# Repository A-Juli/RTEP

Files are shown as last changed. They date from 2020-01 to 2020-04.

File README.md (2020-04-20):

# Yet Another Glove project 

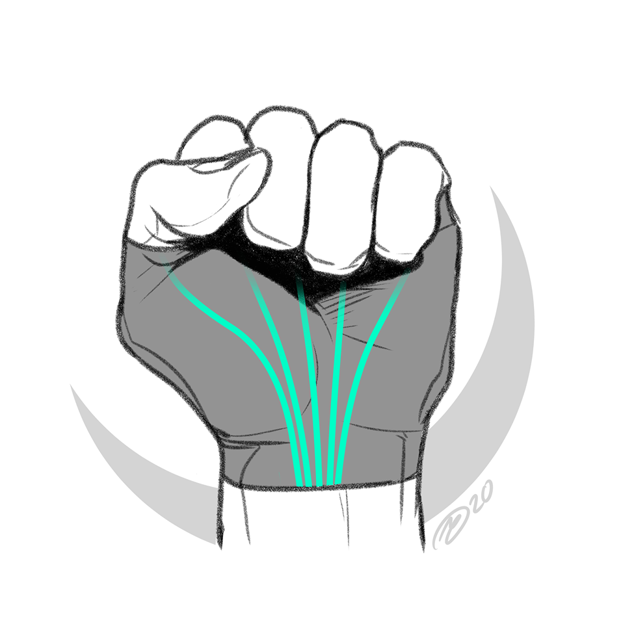
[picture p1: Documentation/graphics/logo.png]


## Description 

Yet Another Glove Project is a wearable glove that is capable of supporting the physiotherapy process by aiding the user in completing exercises for improving finger and tendon strength. 
Using Multiple accelerometer/gyro data, from the MPU6050 sensor, the angle between joint on the hand can be determined and the application will provide the user with feedback showing how close they are to the required angles that the exercise requires. 

The exercises used can be found at Documentation/Exercises.pdf

:star: :star: Psst... we are also live on Facebook! We have our own social media account to ensure further queries/questions are effectively answered! Check it out on: www.facebook.com/YAGPRehab and join the #YAGPRehab crew! :star: :star:

## Build Intructions 

Install QT5, Qwt and wiringPi

```
sudo apt-get install wiringpi
apt-get install qtdeclaratives5-dev-tools
apt-get install libqwt-qt5-dev
```

Clone this repository 

```
git clone https://github.com/A-Juli/RTEP.git
```

To build & Run (GUI)
```
cd RTEP/Software/ExerciseTests/YAGP_GUI/
qmake
make
./YAGP_GUI
```

NOTE: To clean up the files generated such as .o object files, type 'make clean' once finished running the GUI to delete diskspace. (Will require running qmake and make again)

To build & Run (CLI/Terminal/Command Prompt)
```
cd RTEP/Software/ExerciseTests/
make
./Exerciseprogram
```

## Important Notice - COVID19 lockdown
Due to COVID19 the University of Glasgow was closed and  work on the hardware was halted as access to electronics labs have been restricted.
However, before the lockdown various aspects of the hardware and software were completed. 
### Progress of Hardware (before lockdown) 
For the hardware, the design of circuitry and PCBs were completed for the two boards.
Only one board with the MPU6050 had been fully assembled and tested.
This testing involved reading data for the accelerometer from the buffers which would be needed to calculate the angles in the project.

The board with the I2C multiplexer was assembled and tested.
The board was built in the final week before the university was lockdowned and was not working by the time lockdown occured.
Debugging could not be performed due to lack of access to the electronic labs.
Power was provided to the board but no communication over I2C was achieved between the raspberry pi and the main board.
### Progress of Software (before lockdown) 
For the software, programs had been written that allowed the raspberry pi to communicate over I2C and sample data from the MPU6050 registers using a timer. 
Work had been started on the GUI but no significant progress had been made. The GUI itself is composed of two exercises which are simulated/'Unit Tested', and can be found out more in the documentation section of the report. 

### GUI Demo



As shown in the gif, the user can select between which exercise to simulate to show the movement of the hand in terms of angle measurements. The user can also pause the simulation at a certain point in time in order to choose specific values as to where to orient the hand.

### Future Development
When the lockdown ends development and assembly of hardware can be continued.
This would mainly involve the assembly of more MPU6050 boards which is needed to demonstrate a select set of exercises. In terms of GUI, OpenGL Libraries would be used such as Mesa3D in order to track the movement of the hand in realtime as the user moves it, in a mode referred to as: Free Roam. Perhaps more customisability to the UI through using Human Computer Interface methods to get user feedback on how the UI could look nicer, and more user friendly.
## Licenses
This project and all the tools used fall under the GNU Public license. All credits and rights are reserved to their authors. Please refer to the LICENSE.md file in this repo to find out more about the rights of the software. Any future work or modifications done to this project requires to be public.
## Authors
* richardajordan: Hardware and Software design 
* basel-shehabi: Porting our code/software to Qt and using it to make the GUI.
* A-Juli

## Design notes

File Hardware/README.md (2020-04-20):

# Hardware

This project contains three main pieces of hardware.
The Raspberry Pi model B+, a 6D sensor board design are the MPU6050 and a main board with I2C muiltiplexers.

## Overview
This folder contains:
* The main board which is based around the PCA9546AD I2C multiplexer
* The MPU6050 (gyro/accelerometer) board 

## Description 
### MPU6050 Board

MPU6050 board was designed so that it was physically small enough to fit on the joints of the fingers.
The board connects to one of the 4 pin headers located on the main board which provide 5V, ground, SDA and SCL. 

### Main Board

the main board was designed around two PCA9546AD I2C multiplexers, each providing 4 channels. 
This gives 8 different I2C channels and so 16 MPU6050 boards can be accessed by the raspberry pi. The header on the main board takes 5V, GND, SDA and SCL from the raspberry pi.

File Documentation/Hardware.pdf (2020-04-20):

Hardware

For this project, two seperate PCBs were designed to provide the functionally needed to determine the multiple angles between the joints off the hand. The PCBs are to be attached to a glove.

One PCB implements the MPU6050 six dimension sensor (accelerometer/gyro) which is small so that it can be played on each joint of the finger and back of the hand. The MPU6050 uses I2C protocol to communicate with the raspberry pi.

MPU6050

Seen in figure x is the MPU6050 board which was designed so that it was physically small enough to fit on the joints of the fingers. The board connects to one of the 4 pin headers located on the main board which provide 5V, ground, SDA and SCL.

Since the MPU6050 only has two addresses, 0x68 and 0x69, an I2C multiplexer was added to the design to address up to 16 MPU6050 boards. This will be discussed in the next section

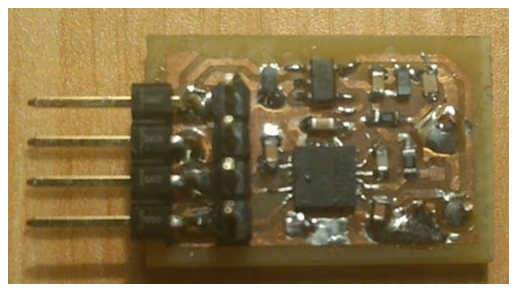
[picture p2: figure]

Main board

Seen in figure x is the main board which is designed around two PCA9546AD I2C multiplexers, each providing 4 channels. This gives 8 different I2C channels and so 16 MPU6050 boards can be accessed by the raspberry pi. The header on the main board takes 5V, GND, SDA and SCL from the raspberry pi.

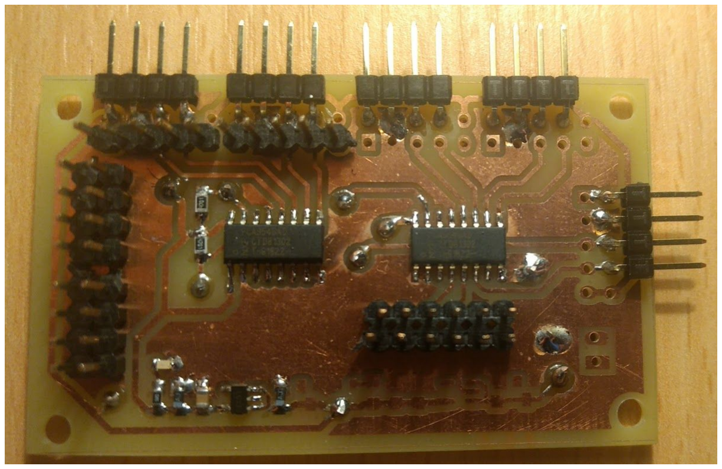
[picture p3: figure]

### 3.2.3 Glove

Both of the PCBs will then be mounted on the glove as shown below. Ideally each joint of the hand would have an MPU6050 board on it. However, due to the COVID-19 lockdown only one board was assembled before access to the labs was denied.

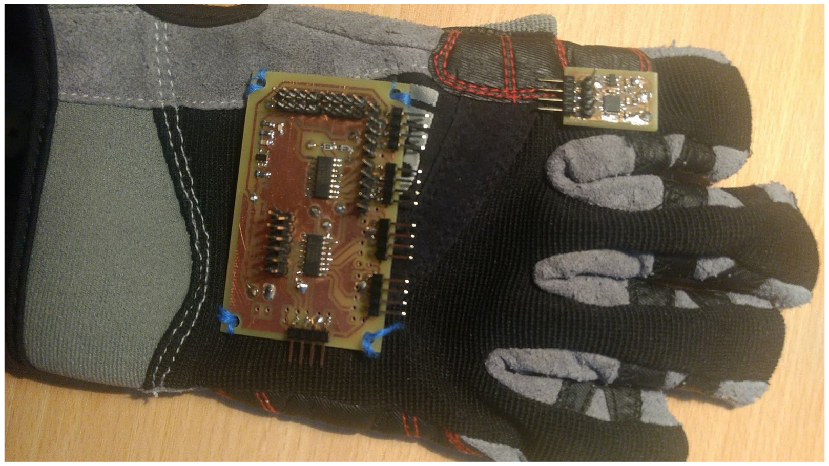
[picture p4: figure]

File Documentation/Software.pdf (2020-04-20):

### 3. Implementation

### 3.1 Software

### 3.1.1 GUI

The GUI itself was built using Qt Creator v5.14 which allowed easy accessibility and modification of what is known as widgets, or objects that a user can interact and use on the screen. The usage of Qt falls under the GNU Public License which would allow us to make our project open source. Qt makes extensive use of inheritance, where all classes are derived from the QObject class which allows for easy manipulation and creation of widgets. It also provides the creator with a signal/slot system as a quick and easy method for implementing event handling and object communication, based on the observer pattern. Qt also provides other technicalities such as threadding support, openGL libraries and many more. All of the code was generated based on looking up documentation found on: https://wiki.qt.io/Main.

### 3.1.2 MPU6050

Located at “RTEP/Software/MPU6050” is example code that reads the data from the MPU6050’s
accelerometer | registers. | This | code | has | been | based | off | of | the
“LSM9DS1_RaspberryPi_CPP_library” git repository created by Bernd Porr. It implements the WiringPi library to communicate over I2C with the MPU6050 board and a timer to control the sampling period. .

### 3.1.3 Unit Tests

Unit tests simulating the data received from the hardware were created since COVID-19 halted further development and assembly for the MPU6050 boards. The required files to run the unit tests are ExerciseTests.cpp and ExerciseTests.h.

This unit test output x,y and z axis data that would be expected from the accelerometers during exercise 1 and 2 described above in section 2.

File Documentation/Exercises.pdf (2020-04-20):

Exercises

This project aims to show the glove measuring angles between various joints on the hand and providing feedback to the user on how they could adjust the position of their hand to obtain the correct positioning for the exercise.

To show how the glove can be used, two exercises were chosen that can be performed as part of physiotherapy to improve strength of the fingers.

Exercise 1

Shown below in figure x is exercise one which requires two accelerometers. At the start of the exercise (shown on the left of figure x) all the accelerometers have an angle of zero between them. The user then bends the knuckle so that the back of the hand and fingers are at 90 degrees (This can be seen to the right of figure x).

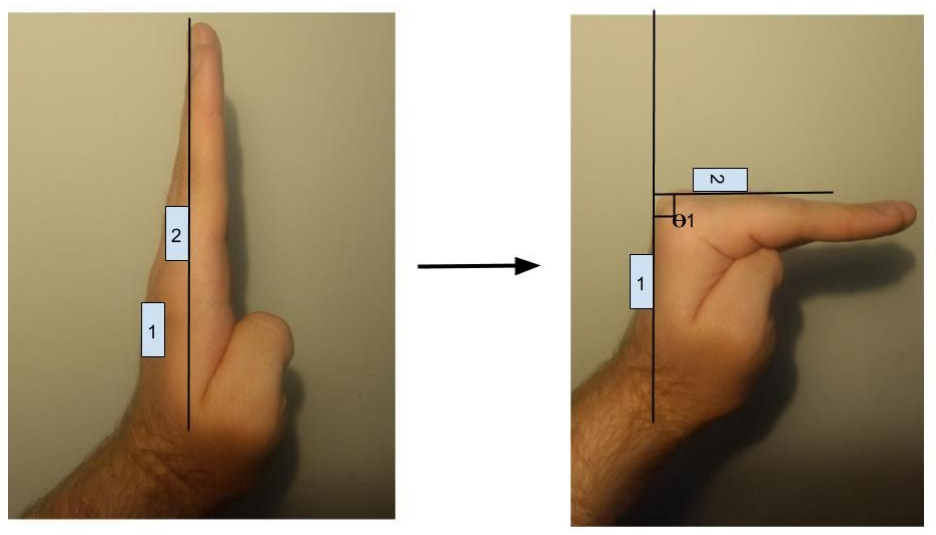
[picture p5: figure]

Exercise 2

Shown below in figure x is exercise two which requires four accelerometers. At the start of the exercise (shown on the left of figure x) all the accelerometers have an angle of zero between them. The user then bends the joints in the fingers into the position seen to the right of figure x. The angles from 2 to 3 and 3 to 4 are required to be as close as possible to 90 degrees.

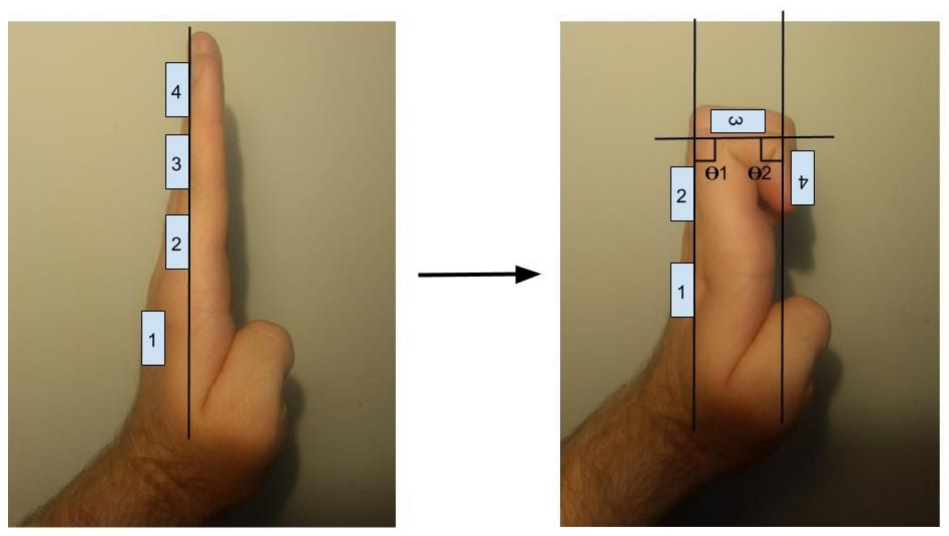
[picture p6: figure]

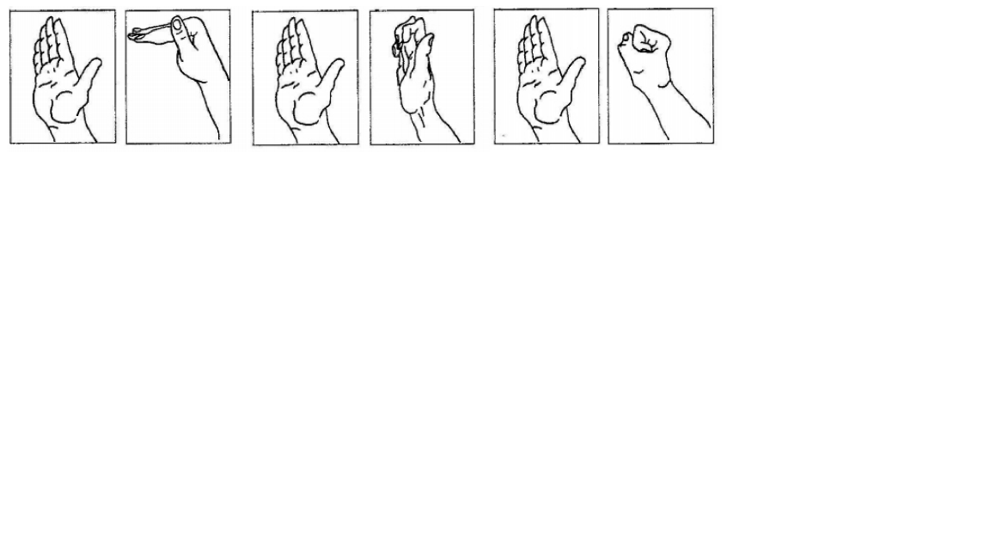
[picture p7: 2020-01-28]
Documentation/graphics/ROM.png

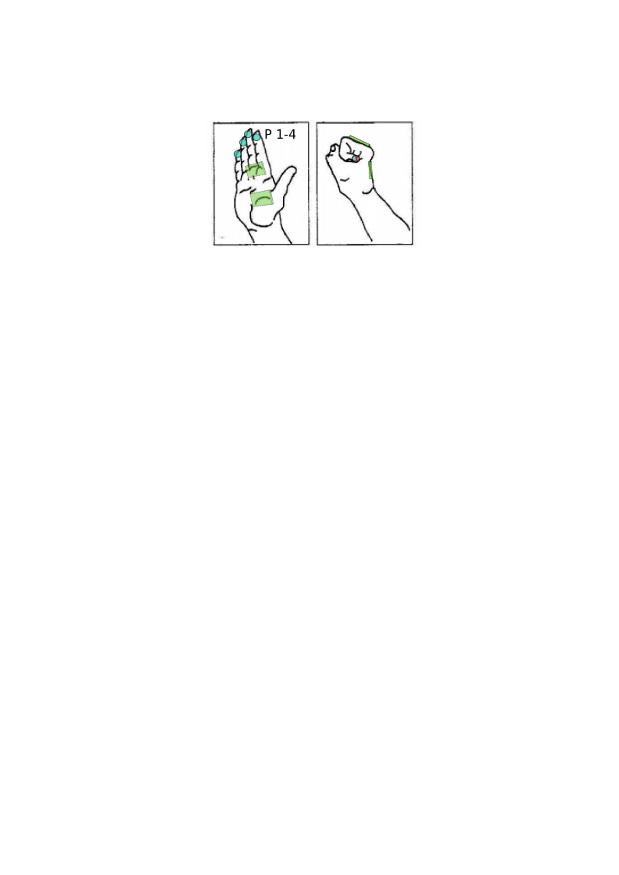
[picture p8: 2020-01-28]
Documentation/graphics/diag2.png

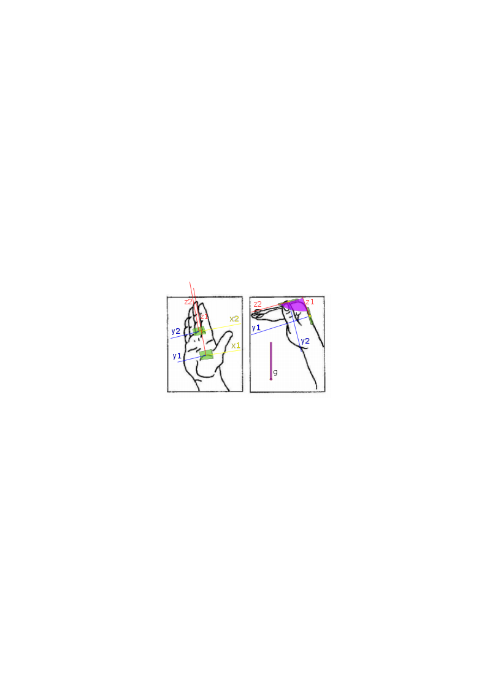
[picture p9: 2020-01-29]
Documentation/graphics/diag1.png

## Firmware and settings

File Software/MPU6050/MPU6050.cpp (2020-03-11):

#include <iostream>
#include <time.h>
#include <unistd.h>
#include <wiringPi.h>
#include <wiringPiI2C.h>
#include "MPU6050.h"
#include "MPU6050Register.h"

using namespace std;

MPU6050::MPU6050(short int addr)
{
    DeviceAdd = addr;
}

uint16_t MPU6050::begin()
{
    Setup();
    uint8_t whoAmI = I2CreadByte(DeviceAdd, WHO_AM_I);
    printf("whoAmI: %i", whoAmI);
    
    if (whoAmI != 0x68) {
	    throw "WhoIAm returns wrong result.";
    }


    uint8_t data;
    data = I2CreadByte(DeviceAdd, 0x6B);
    printf("PWR_MGMT_1: %i\n", data);

    data = I2CreadByte(DeviceAdd, 0x6C);
    printf("PWR_MGMT_2: %i\n", data);
    
    data = I2CreadByte(DeviceAdd, 0x1B);
    printf("Gyro_CONFIG: %i\n", data);
    
    data = I2CreadByte(DeviceAdd, 0x1C);
    printf("Accel_CONFIG: %i\n", data);
    // Gyro initialization stuff:
    //initGyro();    // This will "turn on" the gyro. Setting up interrupts, etc.

    // Accelerometer initialization stuff:
    //initAccel(); // "Turn on" all axes of the accel. Set up interrupts, etc.

    // 20ms => 50Hz
    start(500*1000*1000);
    return whoAmI;
}

void MPU6050::end()
{
    stop();
}

void MPU6050::timerEvent()
{
	readAccel();
	readGyro();
	readTemp();
	count++;
	printf("count: %i\n", count);
	MPU6050Callback->hasSample(
					   calcGyro(gx),
					   calcGyro(gy),
					   calcGyro(gz),
					   calcAccel(ax),
					   calcAccel(ay),
					   calcAccel(az),
					   calcTemp(temperature));
}

void MPU6050::readAccel()
{
	short int temp[6] = {0,0,0,0,0,0};
	
	temp[0] = I2CreadByte(DeviceAdd, OUT_X_accel_m);
	temp[1] = I2CreadByte(DeviceAdd, OUT_X_accel_l);
	temp[2] = I2CreadByte(DeviceAdd, OUT_Y_accel_m);
	temp[3] = I2CreadByte(DeviceAdd, OUT_Y_accel_l);
	temp[4] = I2CreadByte(DeviceAdd, OUT_Z_accel_m);
	temp[5] = I2CreadByte(DeviceAdd, OUT_Z_accel_l);
	
	ax = (temp[0] << 8) | temp[1]; 
        ay = (temp[2] << 8) | temp[3]; 
        az = (temp[4] << 8) | temp[5];
}

float MPU6050::calcAccel(int16_t accel)
{
    return accel/16384.0;
}

void MPU6050::readGyro()
{
	short int temp[6] = {0,0,0,0,0,0};
	
	temp[0] = I2CreadByte(DeviceAdd, OUT_X_gyro_m);
	temp[1] = I2CreadByte(DeviceAdd, OUT_X_gyro_l);
	temp[2] = I2CreadByte(DeviceAdd, OUT_Y_gyro_m);
	temp[3] = I2CreadByte(DeviceAdd, OUT_Y_gyro_l);
	temp[4] = I2CreadByte(DeviceAdd, OUT_Z_gyro_m);
	temp[5] = I2CreadByte(DeviceAdd, OUT_Z_gyro_l);
	
	gx = (temp[0] << 8) | temp[1]; 
        gy = (temp[2] << 8) | temp[3]; 
        gz = (temp[4] << 8) | temp[5];
}

float MPU6050::calcGyro(int16_t gyro)
{
    return gyro/131.0;
}

void MPU6050::readTemp()
{
	uint8_t temp[2] = {0,0};
	
	temp[0] = I2CreadByte(DeviceAdd, OUT_Temp_m);
	temp[1] = I2CreadByte(DeviceAdd, OUT_Temp_l);
	temperature = (temp[0] << 8) | temp[1]; 
}

float MPU6050::calcTemp(int16_t temperature)
{
    return temperature/340+36.53;
}

void MPU6050::initI2C()
{

}

void MPU6050::Setup()
{
    wiringPiSetupGpio();
	
    if ((_fd = wiringPiI2CSetup(DeviceAdd)) < 0)
    {
	cout << "Error" << endl;
    }
    
    close(_fd);
    I2CwriteByte(DeviceAdd, 0x6B,0);
    I2CwriteByte(DeviceAdd, 0x1C,0x0);
    
}


void MPU6050::I2CwriteByte(uint8_t address, uint8_t subAddress, uint8_t data)
{
    _fd = wiringPiI2CSetup(address);
    if (_fd < 0) {
        fprintf(stderr, "Error: I2CSetup failed\n");
        exit(EXIT_FAILURE);
    }
    
    wiringPiI2CWriteReg8(_fd, subAddress, data);
    close(_fd);
}

uint8_t MPU6050::I2CreadByte(uint8_t address, uint8_t subAddress)
{
    _fd = wiringPiI2CSetup(address);
    if (_fd < 0) {
        fprintf(stderr, "Error: I2CSetup failed\n");
        exit(EXIT_FAILURE);
    }
    
    uint8_t data; 
    wiringPiI2CWrite(_fd, subAddress);
    data = wiringPiI2CRead(_fd);                
    close(_fd);
    return data;                           
}

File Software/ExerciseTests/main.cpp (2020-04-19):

#include <iostream>
#include <math.h>
#include "ExerciseTests.h"


using namespace std;

int main()
{
    int q = 0;
    ExerciseTests Test;
    
    // Exercise One

    //Test.setAccel1(0,0,1);
    //Test.setAccel2(0,0,1);

    //Instead of loop us a timer to call whichever Exercise every 50ms
    cout << "Beginning of Exercise 1" << endl; 
    Test.Exercise1Setup();
    cout << "Target Angle: " << Test.TargetAngle[0] << endl;

    for(q=0;q < 10;q++)
    {
        Test.Exercise1();
        cout << "Angle between vectors: " << Test.Angle[0] << endl;
    }

    //Exercise 2

    //Test.setAccel1(0,0,1);
    //Test.setAccel2(0,0,1);
    //Test.setAccel3(0,0,1);
    //Test.setAccel4(0,0,1);

    cout << "Beginning of Exercise 2" << endl;
    Test.Exercise2Setup();
    cout << "Target Angle: " << Test.TargetAngle[0] << " : " << Test.TargetAngle[1] << " : " << Test.TargetAngle[2] << " : " << endl;

    for(q=0;q < 19;q++)
    {
        Test.Exercise2();
        cout << "Angle between vectors: " << Test.Angle[0] << " : " << Test.Angle[1] << " : " << Test.Angle[2] <<  endl;
        //cout << "Dot Product" << Test.DotProduct[0] << " : " << Test.DotProduct[1] << " : " << Test.DotProduct[2] << endl;
    }
}

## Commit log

2020-03-11 Timer for accel acquistion using MPU6050
2020-04-17 UI cleanup... Reworked to work on Raspi
    [main.cpp]
2020-04-19 Hardware for the main board and the MPU6050 board
    [0603design5brd.brd, DESIGN1.DSN, TCA9548APWR.DSN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]
2020-04-20 Added threadding. Fixing layouts
